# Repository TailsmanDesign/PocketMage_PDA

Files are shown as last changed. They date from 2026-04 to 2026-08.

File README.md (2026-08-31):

# PocketMage PDA
PocketMage is available on Crowd Supply! Check it out [here](https://pocketmage.org/back)!

@Ashtf 2025





## [Project Summary]

  This project is a PDA powered by an ESP32-S3 running a custom OS written in C++ using PlatformIO. This project utilizes an E-Ink and OLED screen in tandem to mitigate the refresh rate restrictions of an E-Ink panel while retaining the aesthetics and benefits of using E-Ink. This project is a work in progress and currently amounts to a simple GUI for navigating between apps, a text (.txt) file editor, and a basic file manager. More applications are planned for the future and a list of TO-DOs can be found below.

  At this point, the plan for this project is to get the software and hardware to maturity and once a finished product is achieved, a few things will happen. First, the project files (Code, KiCad schematics, 3D files) will be open-sourced and free for anyone to access. Next, I will likely begin selling kits that allow people to purchase all the parts required to build a device for themselves if they don't want to source the parts themselves. Finally, the community will be encouraged to help develop the software for the device and hopefully push it even further than I could myself.

  I will try my best to keep this GitHub up to date with the development of the device.

## [Getting Started]

Start with the docs site:

- [PocketMage Docs](https://talismandesign.github.io/PocketMage_PDA/docs/)
- [Build Environments](https://talismandesign.github.io/PocketMage_PDA/docs/development/build-environments)
- [Command Manual](https://talismandesign.github.io/PocketMage_PDA/docs/command-manual)
- [FAQ](https://talismandesign.github.io/PocketMage_PDA/docs/faq)
- [Scripting](https://talismandesign.github.io/PocketMage_PDA/docs/scripting)
- [App API Reference](https://talismandesign.github.io/PocketMage_PDA/docs/reference/app-api)

To build or extend apps, start with [APP_TEMPLATE.cpp](./Code/PocketMageOS/src/APP_TEMPLATE.cpp) and the [App API Reference](https://talismandesign.github.io/PocketMage_PDA/docs/reference/app-api).
The app walkthrough video is still useful for a first pass:
[Developing For the PocketMage](https://www.youtube.com/watch?v=3Ytc-3-BbMM)

## [Hardware]

- ESP32-S3 WROOM1 with 16 MB flash and 8 MB RAM. WiFi and Bluetooth supported.
- 3.1" 320x240px 1-bit SPI E-Ink panel (GDEQ031T10) with integrated driver
- 256x32px 1-bit SPI OLED (SSD1326, ER-OLED018-1W) with integrated driver
- MicroSD card slot with support for up to 2 TB
- TCA8418 I2C keyboard matrix IC
- Piezo buzzer (simple tones)
- Power button
- 1200 mAh pouch-style LiPo battery with JST PH (2 mm) connector
- USB Type-C connector
- PCF8563T I2C RTC module
- Expansion port with the following breakouts:
  - +3.3V
  - GND
  - I2C SDA
  - I2C SCL
  - SPI MOSI
  - SPI SCK
  - SPI MISO
  - GPIO A
  - GPIO B
  - GPIO C
  - GPIO D / UART TX (changeable with a solder jumper, default TX)
  - GPIO E / UART RX (changeable with a solder jumper, default RX)

## [Software]

- Text editor app (TXT)
- FileWiz file-management app
- Calendar app
- USB file transfer app
- COMM mesh chat app
- Settings app
- Tasks app
- Journal app
- Dictionary app (Lexicon)
- App loader for OTA apps
- Terminal app (Wrench scripting)
- SSH
- Commands supported through the home menu:
  - `roll dN` (dice roll, N = number of sides)
  - set time and date
  - directly open files in TXT or FileWiz by typing the name
  - and more

## [Planned Features]

- Timers and alarms
- E-book reader
- WiFi notes/calendar sync (Google Docs/Calendar)
- LoRa/Meshtastic add-on module
- Battery expansion add-on module
- Custom abbreviations
- Bluetooth keyboard support

## License

All files are distributed under the Apache-2.0 license:

PocketMage PDA - A clamshell note-taking and productivity device using E-Ink and OLED.



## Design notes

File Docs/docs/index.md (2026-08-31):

---
title: "PocketMage Documentation"
description: "Official documentation for the PocketMage open-source PDA device."
---

# PocketMage Documentation

PocketMageOS docs for the clamshell PDA, the reusable PocketMage Library, and the app workflow built on top of both.

::: tag "PocketMageOS"
::: tag "PocketMage Library"
::: tag "Apps"
::: tag "Commands"

## What is here

::: grids
::: grid
::: card "Getting Started" icon:rocket
Learn what PocketMage is, how to build it, and where to begin.

::: button "Open" ./getting-started/index.md icon:arrow-right
:::
:::
::: grid
::: card "PocketMageOS" icon:cpu
The operating system, app runtime, and navigation flow.

::: button "Open" ./development/index.md icon:arrow-right
:::
:::
::: grid
::: card "Guides" icon:book-open
How to make apps, native apps, OTA apps, and scripts.

::: button "Open" ./guides/index.md icon:arrow-right
:::
:::
::: grid
::: card "Reference" icon:code
The app API, PocketMage Library, and system state.

::: button "Open" ./reference/index.md icon:arrow-right
:::
:::
::: grid
::: card "Commands" icon:keyboard
Keymaps and built-in commands for every app.

::: button "Open" ./command-manual/index.md icon:arrow-right
:::
:::
::: grid
::: card "Features" icon:star
What the device does today and what is still planned.

::: button "Open" ./features/index.md icon:arrow-right
:::
:::
:::

## Quick path

::: steps

1. Read [What is PocketMage](getting-started/what-is-pocketmage.md).
2. Set up the firmware build in [Build Environments](development/build-environments.md).
3. Learn the app model in [Making Apps](guides/making-apps.md).
4. Use the [PocketMage Library](reference/pocketmage-library.md) when you need the hardware wrapper.
5. Keep the [Command Manual](command-manual/index.md) open while testing apps.

:::

## Quick links

- [FAQ](faq/index.md)
- [Scripting](scripting/index.md)
- [GitHub Repository](https://github.com/TalismanDesign/PocketMage_PDA)
- [Discord Community](https://discord.gg/KSCapSf4XH)

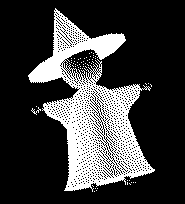
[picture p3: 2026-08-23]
Resources/Assets/Onboarding/onboardMage.bmp

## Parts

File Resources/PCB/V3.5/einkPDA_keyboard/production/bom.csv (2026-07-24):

Designator | Footprint | Quantity | Value | LCSC Part #
BZ1 | BUZ-SMD_3P_L5.0-W5.0-P3.50-TL | 1 | Buzzer | C781883
C1, C20, C4, C6 | 0603 | 4 | 1uF | C15849
C10, C23, C24, C26, C28, C29, C30, C31, C32 | 0805 | 9 | 10uF | C15850
C11 | 0603 | 1 | 4.7pF | C1669
C12, C13, C14, C16 | 1206 | 4 | 4.7uF | C29823
C15, C17 | 0805 | 2 | .1uF | C28233
C18 | 0805 | 1 | 680pF | C1754
C19, C33, C7, C8 | 0402 | 4 | 0.1uF | C1525
C2, C9 | 0805 | 2 | 100nF | C49678
C21, C22, C3 | 0805 | 3 | 22uF | C45783
C25 | 0805 | 1 | 4.7uF | C1779
C27 | 0603 | 1 | 22nF | C21122
C5 | 0805 | 1 | 47uF | C124129
D1 | 0805 | 1 | KT-0805Y | C2296
D2 | D_SOD-123 | 1 | MBR0530 | C77336
D3 | D_SOD-123F | 1 | SM4007 | C64898
D5 | D_SOD-323 | 1 | D_Schottky | C191023
F1 | 1206 | 1 | SMD1206-500-6V | C2760308
FB1, FB2, FB3 | 0603 | 3 | FerriteBead | C85831
J1 | USB-TYPE-C-SMD_TYPE-C-16P-QTWT | 1 | USB_C_Receptacle_USB2.0_16P | C5187472
J2, J5 | AFC01-S12FCA-00 | 2 | Conn_01x12_Pin | C262661
J3 | FPC-SMD_AFC24-S26FIA [DUAL-SIDE] | 1 | Conn_01x26_Pin | C262684
J4 | TF-SMD_503398-1892 | 1 | Micro_SD_Card | C428492
L1 | L_Chilisin_BMRx00060630 | 1 | 10uH | C5189958
L2 | L_Ferrocore_DLG-0504 | 1 | 1uH | C2929426
L3 | L_Wurth_WE-LQSH-3012 | 1 | 2.2uH | C167747
Q1 | SOT-23 | 1 | MMBT3904 | C20526
R1, R14, R17 | 0805 | 3 | 10K | C17414
R11, R16 | 0805 | 2 | 2k | C17604
R12 | 0805 | 1 | 1.8M | C17399
R13 | 0805 | 1 | 205k | C218417
R15, R5 | 0805 | 2 | 470R | C17710
R18 | 0603 | 1 | 10k | C25804
R19, R6, R7 | 0603 | 3 | 100K | C25803
R2, R8 | 0603 | 2 | 100R | C22775
R20 | 0805 | 1 | 680k | C17797
R3 | 0603 | 1 | 4.7k | C23162
R4 | 0603 | 1 | 1k | C21190
RN1, RN2, RN3, RN4, RN5 | R_Array_Concave_4x0603 | 5 | 4x10k | C29718
SW1, SW10, SW11, SW12, SW13, SW14, SW15, SW16, SW17, SW18, SW19, SW20, SW21, SW22, SW23, SW24, SW25, SW26, SW27, SW28, SW29, SW3, SW30, SW31, SW32, SW33, SW34, SW35, SW37, SW38, SW39, SW40, SW5, SW6, SW7, SW9 | contact_pad_SINGLE | 36 | ~
SW2 | contactPad_cutoutR | 1 | ~
SW36, SW41 | KEY-TH_3P-L4.5-W4.5-P3.0-EH | 2 | YTS-C017-2B | C2910872
SW4 | 2X_DIP_DHN-02-V-TR | 1 | SW_DIP_x02 | C224995
SW8 | contactPad_cutoutL | 1 | ~
TH1 | 0603 | 1 | NTC | C76589
TP1, TP2 | TestPoint_Pad_1.0x1.0mm | 2 | TestPoint
U1 | ESP32-S3-WROOM-1 | 1 | ESP32-S3-WROOM-1-N16R2 | C2913205
U10 | UQFN-10_1.4x1.8mm_P0.4mm | 1 | TS3USB30ERSWR | C73880
U2 | SOT-23-6 | 1 | USBLC6-2SC6 | C7519
U3 | Texas_DRC0010J_ThermalVias | 1 | TPS63001 | C28060
U4 | SOIC-8_3.9x4.9mm_P1.27mm | 1 | PCF8563T | C7440
U5 | RTW24_2P45X2P45 | 1 | TCA8418RTWR | C138713
U6 | JST_PH_2P_P2.00mm | 1 | C2764211 | C2764211
U7 | SOT-23-5 | 1 | TPS61040DBV | C7722
U8 | SOT-23-6 | 1 | TPS22917DBV | C2680344
U9 | IC_MP2722GRH-0000-Z | 1 | MP2722GRH-0000-Z | C20099551
Y1 | Crystal_SMD_3215-2Pin_3.2x1.5mm | 1 | Crystal_32.768kHz | C5213671

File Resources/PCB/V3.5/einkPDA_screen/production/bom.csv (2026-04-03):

Designator | Footprint | Quantity | Value | LCSC Part #
C1, C10, C3, C4, C5, C6, C7, C8, C9 | 0402 | 9 | 1uF | C52923
C11 | 0805 | 1 | 4.7uF | C1779
C12, C2 | 0402 | 2 | 4.7uF | C23733
C13, C14 | 0402 | 2 | 0.1uF | C1525
D1, D2, D3 | D_SOD-123 | 3 | MBR0530 | C77336
J2 | AFE03-S25FMA-1H | 1 | ~ | C262544
J3 | TouchSlider-9_50x10mm | 1 | CapacitiveTouch
J4 | AFC01-S12FCA-00 | 1 | Conn_01x12_Pin | C262661
L1 | L_Cenker_CKCS5020 | 1 | 10uH | C52281
Q1 | SOT-323_SC-70 | 1 | Si1308EDL | C7603347
R1 | 0603 | 1 | 0.47R | C3013349
R2 | 0805 | 1 | 10k | C17414
R3 | 0603 | 1 | 75k | C23242
RN1 | R_Array_Concave_4x0603 | 1 | 4x10k | C29718
U1 | UQFN-20_3x3mm_P0.4mm | 1 | MPR121QR2 | C91322

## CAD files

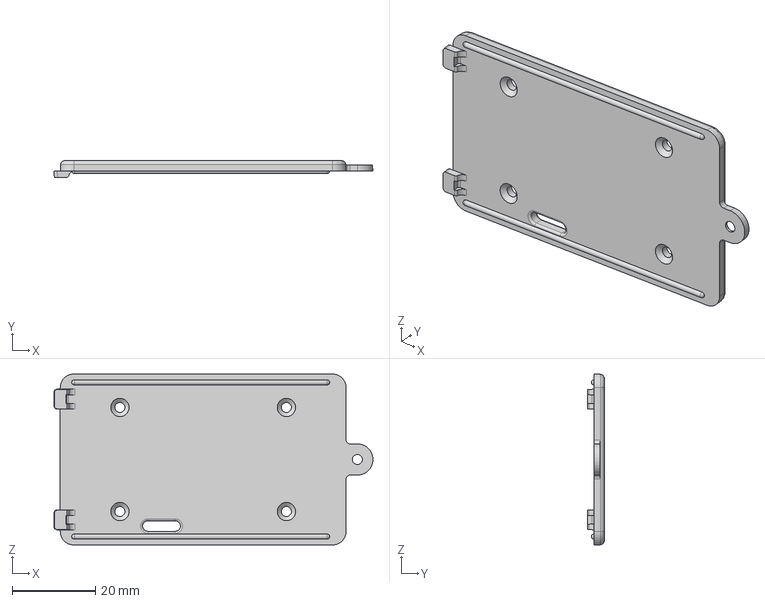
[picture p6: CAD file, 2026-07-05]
Resources/CAD/V3.4 FDM Friendly/batteryDoorFDM.step
76.6 x 4.00 x 41.1 mm

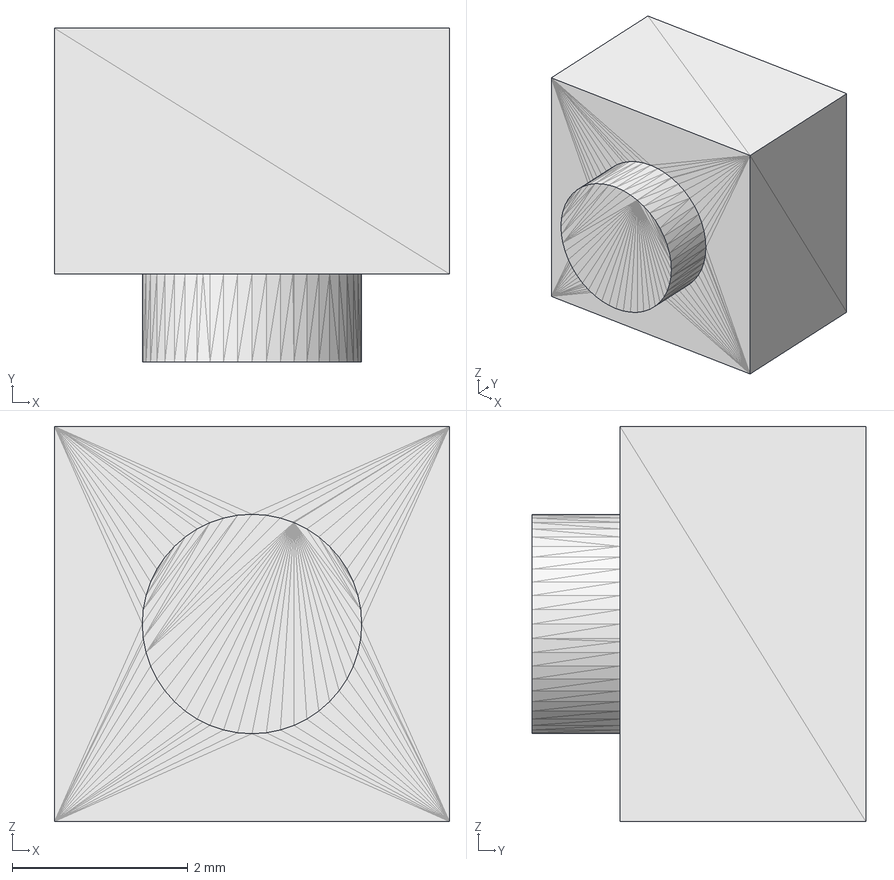
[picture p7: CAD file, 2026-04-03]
Resources/PCB/V3.5/einkPDA_keyboard/JLC_Parts/YTS-C017-2B.step
4.50 x 3.80 x 4.50 mm

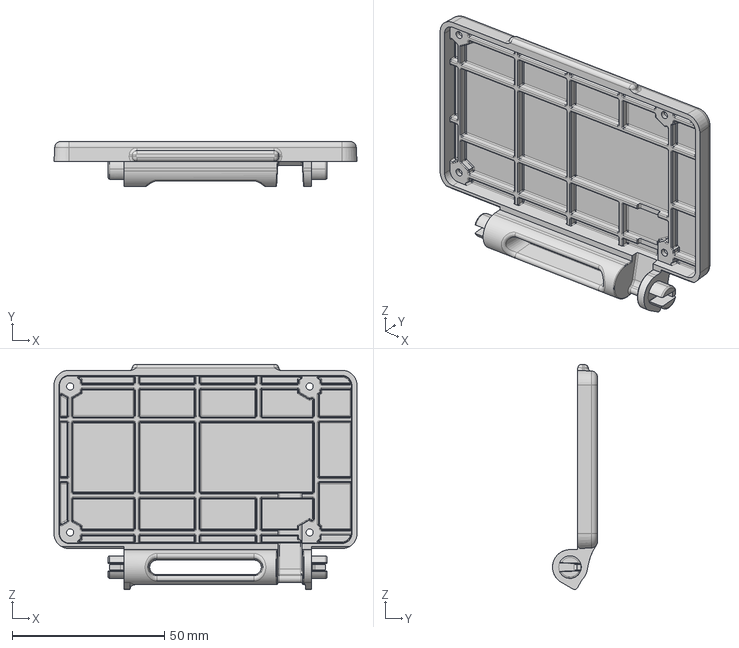
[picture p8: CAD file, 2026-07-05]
Resources/CAD/V3.4 FDM Friendly/frameLidFDM.step
99.6 x 14.8 x 74.0 mm

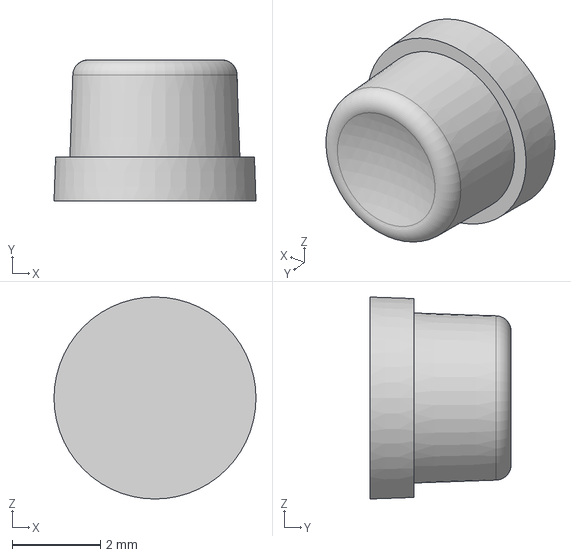
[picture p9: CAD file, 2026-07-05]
Resources/CAD/V3.4 FDM Friendly/resetButtonFDM.step
4.57 x 3.20 x 4.57 mm

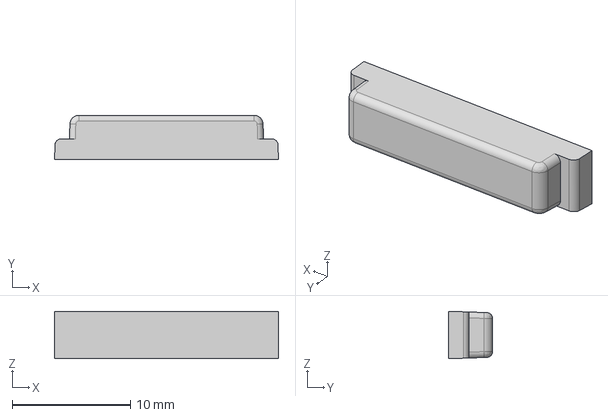
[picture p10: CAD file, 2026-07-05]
Resources/CAD/V3.4 FDM Friendly/powerButtonFDM.step
19.0 x 3.75 x 4.02 mm

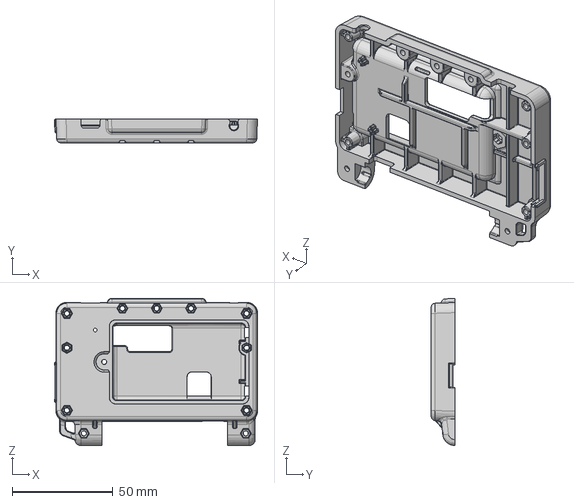
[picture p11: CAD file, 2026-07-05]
Resources/CAD/V3.4 FDM Friendly/bottomFrameFDM.step
100.5 x 11.7 x 72.8 mm

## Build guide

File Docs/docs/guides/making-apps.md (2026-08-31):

---
title: "Making Apps"
description: "How to create PocketMage apps, both native and OTA."
---

# Making Apps

PocketMage apps come in two forms: native apps that ship inside PocketMageOS, and OTA apps that are loaded onto the device later. The two share the same core shape, so this page walks through that shape once and then explains where the paths diverge.

::: grids
::: grid
::: card "Native apps" icon:terminal
Compiled into the OS and wired into the app dispatch switch.
:::
:::
::: grid
::: card "OTA apps" icon:package
Compiled separately and loaded into one of four OTA slots at runtime.
:::
:::
::: grid
::: card "Same shape" icon:code
Both are three functions: init, handle input, draw.
:::
:::
:::

## The basic app shape

Every PocketMage app has the same three jobs, and they map directly to three functions.

1. **Initialize state** - run once when the app opens. Set up whatever the app needs and mark the screen for a redraw.
2. **Process keyboard input** - run on every keypress. Read the key, update app state, and queue a redraw.
3. **Draw the screen** - run when the E-Ink needs to update. Render the current app state.

This pattern is visible in `Code/PocketMageOS/include/globals.h` (the prototypes) and in the app files under `Code/PocketMageOS/src/OS_APPS/`.

## Start with the template

The app template is your starting point:

- [APP_TEMPLATE.cpp](https://github.com/TalismanDesign/PocketMage_PDA/blob/main/Code/PocketMageOS/src/APP_TEMPLATE.cpp)

It defines the three entry points an OTA app needs:

```cpp
#include <globals.h>
#if OTA_APP
void APP_INIT() {
  // 1. set up app state
}

void processKB_APP() {
  // 2. handle a keypress
}

void einkHandler_APP() {
  // 3. draw the screen
}
#endif
```

## Building the app step by step

1. **Decide native vs OTA.** If the app belongs to the device experience, make it native. If it is third-party or experimental, make it an OTA app so it can be installed and removed without reflashing the OS.
2. **Pick the shared helpers.** Browse the [PocketMage Library](../reference/pocketmage-library.md) before writing anything. Prompts (`textPrompt()`), file selection (`fileWizardMini()`), and timeouts (`checkTimeout()`) already exist; do not reimplement them.
3. **Wire it into the OS (native only).** Add an `AppState` entry, the three prototypes, and the `switch` cases marked `// ADD APP CASES HERE` in `PocketMageV3.cpp`. Then add a home-screen command if you want it launchable by name.
4. **Test the keyboard path first.** Get a keypress into your handler and onto the OLED before worrying about the E-Ink.
5. **Test the E-Ink path second.** Make sure drawing and refresh behave, including fast partial refreshes.
6. **Check timeout, wake, and save last.** Confirm the app resets the idle clock, handles sleep/wake without corrupting state, and saves before exit where it should.

## Good app rules

- Keep app state local and explicit; do not scatter globals.
- Use shared helpers instead of duplicating them.
- Keep draw code separate from input code.
- Make exit, save, and sleep behavior obvious.
- For native apps, follow the existing app in `src/OS_APPS/` that does the closest job.

## Native vs OTA: which path

| | Native | OTA |
| --- | --- | --- |
| Where the code lives | `src/OS_APPS/` inside PocketMageOS | Standalone project using `APP_TEMPLATE.cpp` |
| How it is built | With the OS (`PM_PRODUCTION`/`PM_BETA`) | With the `OTA_APP` environment |
| How it ships | Flashed as part of the firmware | Packaged as a `.tar` and loaded through the app loader |
| Dispatch | Wired into the switch in `PocketMageV3.cpp` | Entry points called by the loader |
| Hardware access | PocketMage Library | PocketMage Library |

Read the [Native Apps](native-apps.md) and [OTA Apps](ota-apps.md) pages for the details of each path.

## Next steps

::: grids
::: grid
::: button "Native Apps" ./native-apps.md icon:terminal
:::
::: grid
::: button "OTA Apps" ./ota-apps.md icon:package
:::
::: grid
::: button "App API Reference" ../reference/app-api.md icon:book
:::
::: grid
::: button "PocketMage Library" ../reference/pocketmage-library.md icon:box
:::
:::

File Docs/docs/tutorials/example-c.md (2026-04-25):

---
title: "PocketMage Script Example: Basic Input/Output"
description: "A simple PocketMage script demonstrating user input, OLED output, and terminal printing."
---

# Scripting Example: Basic Input/Output

```c
// PocketMage scripting example
// Based on Wrench by jingoro2112 (GH)
// Edit with potion: pot example.c
// Compile and run: brew example.c

// Declare a variable
var x = ""; // "" indicates str

// Prompt user to enter number
// Set x to entered number
x = prompt("Enter a number");

// Display x on OLED
oledWord(x);

// Print x to terminal
print(x);

// Update the terminal
// (refresh the OLED)
updateTerm();

// Initialize an iteration var i
var i = 0;

// Loop while i < x
// Us toInt to convert str to int
while (i < toInt(x)) {
  // Iterate
  i = i + 1;

  // Display i on OLED
  oledWord(i);

  // Wait 500ms
  delay(500);
}

// Print the final i to the term
print(i);

// Generate a random number
var randomInt = random(0, 100);
print("Random Number: " + randomInt);

// Update the terminal
// (refresh the OLED)
updateTerm();
```

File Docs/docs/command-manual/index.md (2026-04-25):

---
title: "PocketMage Command Manual"
description: "Keystrokes and command reference for the PocketMage PDA."
---

# PocketMage Keystrokes Guide

This is a guide on common key combinations and commands on the PocketMage PDA device. The guide is split up into sections based on application.

---

## General Keystrokes (work in almost any app)

- **( < )** | Cursor left
- **( > )** | Cursor right
- **(SHIFT) + ( < )** | Cursor to start of line
- **(SHIFT) + ( > )** | Cursor to end of line
- **(FN) + ( o )** | Clear line
- **(FN) + ( < )** | Exit or back button
- **(FN) + ( > )** | Save document
- **(SHIFT) + (key)** | Capital letter
- **(FN) + (Key)** | FN layer keymapping (legends on the PCB)
- **(FN) + (SHIFT) + (Key)** | FN+SHIFT layer keymapping
- **( o ) OR (ENTER)** | Select button

---

## Keymap

### Default Layer

```txt
[q] [w] [e] [r] [t] [y] [u] [i] [o] [p]
[a] [s] [d] [f] [g] [h] [j] [k] [l] [BKSP]
[TAB] [z] [x] [c] [v] [b] [n] [m] [.] [ENTER]
[SHIFT] [FN] [SPACE] [<] [o] [>]
```

### Shift Layer

```txt
[Q] [W] [E] [R] [T] [Y] [U] [I] [O] [P]
[A] [S] [D] [F] [G] [H] [J] [K] [L] [BKSP]
[TAB] [Z] [X] [C] [V] [B] [N] [M] ['] [ENTER]
[SHIFT] [FN] [SPACE] [SHIFT+<] [SHIFT+o] [SHIFT+>]
```

### Function Layer

```txt
[1] [2] [3] [4] [5] [6] [7] [8] [9] [0]
[#] [!] [$] [:] [;] [(] [)] [&] ["] [BKSP]
[FN+TAB] [%] [_] [+] [-] [*] [/] [?] [,] [ENTER]
[SHIFT] [FN] [SPACE] [FN+<] [FN+o] [FN+>]
```

### Function + Shift Layer

```txt
[!] [@] [#] [$] [%] [^] [&] [*] [(] [)]
[~] [`] [|] [[] []] [{] [}] [<] [>] [BKSP]
[FN+TAB] [%] [=] [&] [+] [-] [\] [?] [,] [ENTER]
[SHIFT] [FN] [SPACE] [FN+SHIFT+<] [FN+SHIFT+o] [FN+SHIFT+>]
```

---

## While Sleeping

### Bypass home and directly enter an app

You can bypass the home menu and enter directly into an app and wake up with one keystroke. Pressing the buttons below while PocketMage is sleeping will wake the device and boot into the corresponding app.

- **( SPACE )** - Return to previous app (saved state from last sleep)
- **( H )** - Home
- **( U )** - USB
- **( F )** - Filewiz
- **( T )** - Tasks
- **( N )** - TXT
- **( S )** - Settings
- **( C )** - Calendar
- **( J )** - Journal
- **( D )** - Dictionary (lexicon)
- **( L )** - Loader

---

## Home App

### Entering an OS app

Type an app's name to enter that app. For example, to enter calendar, type "calendar". You can type the name as it appears on the screen or use a shortcut. For example, typing "cal" also enters the calendar.

### Entering a 3rd party app

For 3rd party apps, type the letter of the slot that app is installed in. For example if you have the Calc app installed in the first app slot, type "a" to enter the app.

### Other commands

Many other commands can be done from the homescreen, including all of the settings commands and some other fun ones for you to discover!

---

## TXT App

- **(FN) + ( < )** | Exit app
- **(FN) + ( > )** | Save document
- **(FN) + ( o )** | Enter filesystem (loading files)
- **(SHFT) + ( o )** | New blank text document
- **(FN) + (Key)** | FN layer keymapping (legends on the PCB)
- **(SHFT) + (key)** | Capital letter
- **(ENTER)** | Create a new line
- **(SHFT) + ( < )** | Change text style (body, heading, etc.)
- **(SHFT) + ( > )** | Change formatting (bold, italics, etc.)
- **Scroll Bar** | Swipe up or down to scroll through the document

---

## FILEWIZ

- **(FN) + ( < )** | Exit app
- **( < ) AND ( > )** | Scroll left and right
- **( o ) OR (ENTER)** | Select file or folder
- **( 0 ) TO ( 9 )** | Select recent file
- **( BKSP )** | Go back a filesystem level

---

## USB

Plug in the PocketMage to your PC to view the files. Eject and exit the app when you're finished.

- **(FN) + ( < )** | Exit app

---

## Settings

Type the setting as it appears on the screen to change it. Some examples are given below. Note: all settings are case-insensitive, meaning that you can type in all lowercase. All of these settings are also available from the home menu command bar if you memorize them.

- TimeSet [HH]:[MM] -> TimeSet 15:46
- DateSet YYYYMMDD -> DateSet 20251230
- ShowYear [bool] -> ShowYear t
- Timeout [int] -> Timeout 300
- **(FN) + ( < )** | Exit app

---

## Tasks

- **( N )** | Create a new task, follow on-screen prompts
- **(ENTER)** | Enter information into prompt
- **( 0 ) TO ( 9 )** | Select task for editing
- **(FN) + ( < )** | Exit app

---

## Calendar

Type commands to navigate dates or create events. All commands are case-insensitive.

### Month View

- **jan 2025 / feb 2030 / etc.** | Jump to month and year
- **20251225** | Jump to exact date (YYYYMMDD)
- **14** | Jump to a day in the current month
- **( N )** | New event
- **(FN) + ( < )** | Exit app

### Week View

- **sun, mon, tue, wed, thu, fri, sat** | Jump to weekday in the viewed week
- **( N )** | New event
- **(FN) + ( < )** | Exit app

### Day View

- **( N )** | New event for selected day
- **1, 2, 3, ...** | Open event by index
- **(FN) + ( < )** | Exit app

### Repeating Events

- **no** | No repeat
- **daily** | Repeat every day
- **weekly xx** | Repeat every week, **xx** is one or more of **mo**, **tu**, **we**, **th**, **fr**, **sa**, **su**
- **monthly xx** | Repeat monthly, **xx** is the day of the month (1-31) or ordinal weekday (ex. **2tu** = the second Tuesday of each month)
- **yearly xx** | Repeat every year, **xx** is month and day of the month (ex. **apr22**)

---

## Journal

Type a date to open or create a journal entry. Commands are case-insensitive.

- **( T )** | Open today’s journal entry
- **YYYYMMDD - Example: 20250314** | Open/create entry for exact date
- **jan 1 / feb 12 / etc.** | Open/create entry for given month and day (uses current year)
- **(FN) + ( < )** | Exit app

---

## Lexicon

Type a word to search the dictionary. Matches are loaded from the SD card. Commands are case-insensitive.

- **Type any word** | Search for definitions (example: abandon)
- **(ENTER)** | Execute search
- **( < ) OR ( > )** | Previous / next definition
- **(FN) + ( < )** | Exit app

---

## App loader

Manage and install .tar apps to OTA slots. Commands are case-insensitive.

- **A / B / C / D** | Select OTA slot to edit
- **( S )** | Swap app in selected slot (choose a .tar file)
- **( D )** | Delete app in selected slot
- **(FN) + ( < )** | Exit app / return to menu
- **Progress Bar** | Shows extraction (0–50%) and installation (50–100%) status

---

## Sleep Modes

When on battery, save power and look at a random screensaver. When charging, view a clock, upcoming tasks, and weather (work in progress)

### Sleep (when not plugged into usb)

- **sleep button** to enter sleep
- **any key on keyboard** to wake

### Now-Later (when usb is plugged in)

- **sleep button** to enter now-later
- **sleep button** to wake

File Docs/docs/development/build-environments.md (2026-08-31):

---
title: "Build Environments & PlatformIO Setup"
description: "How to set up PlatformIO and build PocketMage firmware on Linux, macOS, and Windows."
---

# Build Environments & PlatformIO Setup

PocketMage firmware is built with [PlatformIO](https://platformio.org/). The build configuration lives in `Code/PocketMageOS/platformio.ini` and defines three environments that produce different firmware images from the same source.

## The three build environments

| Environment | Target | Purpose |
| --- | --- | --- |
| `PM_PRODUCTION` | Production hardware (N16R2, Quad PSRAM enabled) | The stable OS image flashed to production devices |
| `PM_BETA` | Beta hardware (N16R8, PSRAM forced disabled) | A test build with the latest changes |
| `OTA_APP` | Hardware-agnostic | A single third-party app built to be sideloaded |

The three environments share a common `[common]` section and differ only in build flags. The flags set three things: which hardware revision to target, whether the build is an OS or an OTA app, and the version string.

Running `pio run` with no arguments builds all three. Build one explicitly with `pio run -e <name>`.

### What the OTA_APP flag does

The `OTA_APP` environment defines `OTA_APP_FLAG=1`. In `config.h` this becomes `OTA_APP == true`, which excludes the native OS app set from the build. The three entry points from [APP_TEMPLATE.cpp](https://github.com/TalismanDesign/PocketMage_PDA/blob/main/Code/PocketMageOS/src/APP_TEMPLATE.cpp) - `APP_INIT()`, `processKB_APP()`, `einkHandler_APP()` - become the program. The same source tree therefore builds either a full OS or a standalone app depending on the environment you choose.

## Prerequisites

- [VS Code](https://code.visualstudio.com/) installed
- Python 3 installed
- PlatformIO Core (installed automatically by the VS Code extension, or via `pip install platformio`)
- The PocketMage source code, cloned from [GitHub](https://github.com/TalismanDesign/PocketMage_PDA)

The ESP32 platform support downloads automatically on the first build, so the first build is noticeably slower.

## Setup

### Linux

1. Install `python3-venv` if it is missing:

   ```bash
   sudo apt install python3-venv
   ```

2. Install the [PlatformIO IDE](https://docs.platformio.org/en/latest/integration/ide/vscode.html#ide-vscode) extension in VS Code.
3. Open the PocketMage source folder in VS Code.
4. When PlatformIO asks for a project folder, choose `Code/PocketMageOS/`.
5. Build from the PlatformIO toolbar or the command palette.

### macOS

Use the same steps as Linux. No extra setup is required.

### Windows

1. Install [Git](https://git-scm.com/) to clone the repository.
2. Follow the same PlatformIO IDE steps as Linux.
3. Build from the PlatformIO toolbar in VS Code.

## Command line

From `Code/PocketMageOS/`:

```bash
pio run -e PM_PRODUCTION   # production firmware
pio run -e PM_BETA         # beta firmware
pio run -e OTA_APP         # a third-party OTA app
```

## OTA apps

OTA apps use the `OTA_APP` environment, which switches the build into app mode as described above. The app is packaged as a `.tar` file and installed on the device through the app loader. See [OTA Apps](../guides/ota-apps.md) and the [app loader section](../command-manual/index.md) of the command manual.

For a full walkthrough, watch the [OTA app development video](https://www.youtube.com/watch?v=3Ytc-3-BbMM).

## Testing

There is no automated test suite for the firmware. Verify changes against real hardware, or review the build log for changes with no runtime effect. CI builds `PM_PRODUCTION` and `PM_BETA` on every push, so a clean build locally is the minimum bar before opening a pull request.

## Next steps

::: grids
::: grid
::: button "PocketMageOS overview" ./index.md icon:cpu
:::
::: grid
::: button "Making Apps" ../guides/making-apps.md icon:code
:::
::: grid
::: button "OTA Apps" ../guides/ota-apps.md icon:package
:::
::: grid
::: button "Firmware FAQ" ../faq/index.md icon:help-circle
:::
:::

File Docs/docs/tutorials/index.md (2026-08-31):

---
title: "PocketMage Tutorials"
description: "Step-by-step guides for PocketMage setup and configuration."
---

# Tutorials

These pages cover hands-on setup tasks.

## Guides

- [Format a MicroSD Card](format-micro-sd.md)

## Development

- [Build Environments & PlatformIO Setup](../development/build-environments.md)
- [OTA App Template](https://github.com/TalismanDesign/PocketMage_PDA/blob/main/Code/PocketMageOS/src/APP_TEMPLATE.cpp)

## Scripting

- [Scripting Overview](../scripting/index.md)
- [Full Wrench Command List](../scripting/fullPotionCommandList.md)

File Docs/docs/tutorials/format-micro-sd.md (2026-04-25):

---
title: "Format a MicroSD Card for PocketMage"
description: "Guide to formatting SD cards for compatibility with PocketMage."
---

# PocketMage SD Card Formatting Guide

**WARNING**  
These steps will ERASE the SD card. Back up your data first.

This guide ensures SD cards are formatted in a way that is compatible with the PocketMage device.

---

## Supported SD Card Requirements

- **Card size:** 2 GB – 32 GB microSD
- **Filesystem:** FAT32
- **Partition scheme:** MBR (Master Boot Record)
- **Partitions:** Single primary partition
- **Cluster (allocation unit) size:** 32 KB
- **Sector size:** 512 bytes (default)

X exFAT is NOT supported  
X GPT partition tables are NOT supported  
X 64 GB+ cards are NOT recommended unless you explicitly force FAT32 + MBR

---

## Windows (Recommended)

### Step 1 — Open diskpart

1. Insert the SD card
2. Open **Command Prompt as Administrator**
3. Run:
   diskpart

### Step 2 — Identify the SD card

list disk

Find the disk number that matches your SD card size.

**Make sure you select the correct disk.**

### Step 3 — Format the card (MBR + FAT32)

select disk X
clean
convert mbr
create partition primary
format fs=fat32 unit=32k quick
assign
exit

### Step 4 — Verify (optional)

- Open **Disk Management**
- Right-click the disk → Properties → Volumes
- Partition style must say **Master Boot Record (MBR)**

---

## macOS (Terminal — NOT Disk Utility)

macOS Disk Utility often creates GPT layouts that do not work.

### Step 1 — Identify the SD card

diskutil list

Find the disk number (example: disk2).

### Step 2 — Erase and create MBR + FAT32

diskutil eraseDisk FAT32 PM_SD MBRFormat /dev/disk2

### Step 3 — Force 32 KB cluster size

sudo newfs_msdos -F 32 -c 64 /dev/disk2s1

Explanation:  
-c 64 = 64 × 512-byte sectors = 32 KB clusters

### Step 4 — Verify

diskutil info /dev/disk2 | grep "Partition Map"

Must say:
Partition Map Scheme: Master Boot Record

---

## Linux

### Step 1 — Identify the SD card

lsblk

Example device: /dev/sdb

### Step 2 — Remove existing partition data

sudo wipefs -a /dev/sdb

### Step 3 — Create MBR partition table

sudo parted /dev/sdb --script mklabel msdos
sudo parted /dev/sdb --script mkpart primary fat32 1MiB 100%

### Step 4 — Format FAT32 with 32 KB clusters

sudo mkfs.fat -F 32 -s 64 /dev/sdb1

### Step 5 — Verify

lsblk -o NAME,SIZE,PTTYPE

PTTYPE must be dos.

---

## Final Checklist

Before using the card in PocketMage, confirm:

- FAT32 filesystem
- MBR partition table (not GPT)
- One primary partition
- 32 KB cluster size
- Card size ≤32 GB

If any of these are incorrect, the card may not be detected.

---

If issues persist after following this guide, the SD card itself may be incompatible.

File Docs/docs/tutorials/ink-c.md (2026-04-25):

---
title: "PocketMage Script Example: E-Ink Drawing"
description: "A PocketMage script demonstrating drawing shapes and text on the E-Ink display."
---

# Scripting Example: E-Ink Drawing

```c
// PocketMage E-Ink scripting example
// Based on Wrench by jingoro2112 (GH)
// Edit with potion: pot ink.c
// Compile and run: brew ink.c
// Colors/clr: 1 - Black, 0 - White

delay(1000);

// Draw shapes on a white background
inkBackground(0); //Background clr
inkRect(10, 20, 50, 25, 1, 0); //x,y,w,h,line clr,fill clr
inkCircle(100, 50, 30, 1, 1); //x,y,r,line clr,fill clr
inkText(10, 100, 2, 1, "PocketMage!"); //x,y,font size,text
updateInk(); //Update E-Ink display

delay(3000);

// Draw shapes on a black background
inkBackground(1); //Background clr
inkRect(20, 10, 25, 50, 0, 1); //x,y,w,h,line clr,fill clr
inkCircle(120, 60, 35, 0, 0); //x,y,r,line clr,fill clr
inkText(30, 120, 3, 0, "Hello World!"); //x,y,font size,text
updateInk(); //Update E-Ink display

delay(3000);
```

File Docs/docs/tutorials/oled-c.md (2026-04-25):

---
title: "PocketMage Script Example: OLED Drawing"
description: "A PocketMage script demonstrating drawing shapes and text on the OLED display."
---

# Scripting Example: OLED Drawing

```c
// PocketMage OLED scripting example
// Based on Wrench by jingoro2112 (GH)
// Edit with potion: pot ink.c
// Compile and run: brew ink.c
// Colors/clr: 1 - Black, 0 - White

delay(1000);

// Draw shapes on a white background
oledBackground(0); //Background clr
oledRect(10, 20, 25, 5, 1, 0); //x,y,w,h,line clr,fill clr
oledCircle(100, 10, 10, 1); //x,y,r,line clr
oledText(180, 20, 2, 1, "PocketMage!"); //x,y,font size,text
updateOled(); //Update OLED display

delay(3000);

// Draw shapes on a black background
oledBackground(1); //Background clr
oledRect(10, 20, 25, 5, 0, 1); //x,y,w,h,line clr,fill clr
oledCircle(100, 10, 10, 0); //x,y,r,line clr
oledText(120, 20, 3, 0, "Hello World!"); //x,y,font size,text
updateOled(); //Update OLED display

delay(3000);
```

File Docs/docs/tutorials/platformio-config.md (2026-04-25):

---
title: "Setting Up a PocketMage Build Environment"
description: "How to set up PlatformIO and build PocketMage firmware on Linux, Mac, and Windows."
---

# Setting Up a Pocket Mage Build Environment

## Prerequisites

- VS Code is installed.
- python3 is installed.
- You have a directory with the Pocket Mage source code. This could be directly cloned from the main repo. If you plan on contributing back (and you should) this will be simplified if you first fork the repo and then clone from your own fork.

## Set up a Linux Build Environment

The Pocket Mage project has some information about building the project [in this video](https://www.youtube.com/watch?v=3Ytc-3-BbMM). However, there are some assumptions about what you have provisioned that will probably not be true for most viewers. These are the steps to get a functioning PlatformIO environment such that at 1:04 when he says "We're just going to hit this button" you have a button to hit.

1. Note: This step is for **Linux only**. Probably most people who want to build Pocket Mage already have python3 but my Pop_OS Linux Laptop did not have python3-venv by default. I used [these directions](https://github.com/platformio/platformio-core-installer/issues/85) to get that installed.
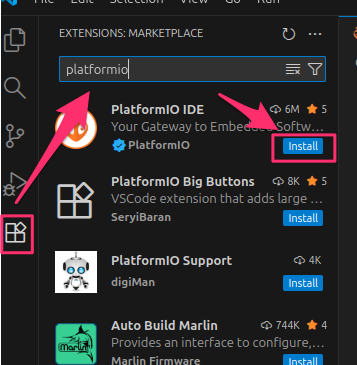
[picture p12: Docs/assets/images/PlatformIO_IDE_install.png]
The Extenstion Marketplace in VS Code
2. You will need the [PlatformIO IDE](https://docs.platformio.org/en/latest/integration/ide/vscode.html#ide-vscode) extension installed in your VS Code. In the Extensions marketplace, search for "PlatformIO IDE" and install it. This will take a little bit of time. After it completes you will be instructed to restart VS Code. 
3. Mark the directory you want to build as a PlatformIO Project.
   - Click the "Pick a Folder" option. You will need an existing platformio.ini config file for this to work. For the first time, try selecting the "BlankApp" folder.

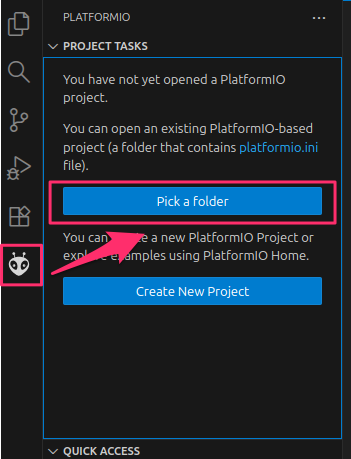
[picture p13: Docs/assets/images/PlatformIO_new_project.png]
The Pick a Folder option in the PlatformIO IDE
   
   - Based on the values of the configuration, many packages will be installed. I found that this took some time with my computer and internet speeds. Expect this to be a good point for a beverage or maybe a meal.

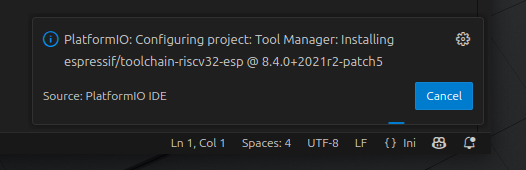
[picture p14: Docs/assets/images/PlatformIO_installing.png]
The status window of PlatformIO creating a project
   

4. Now you can build, by using the drop-down at the upper right.

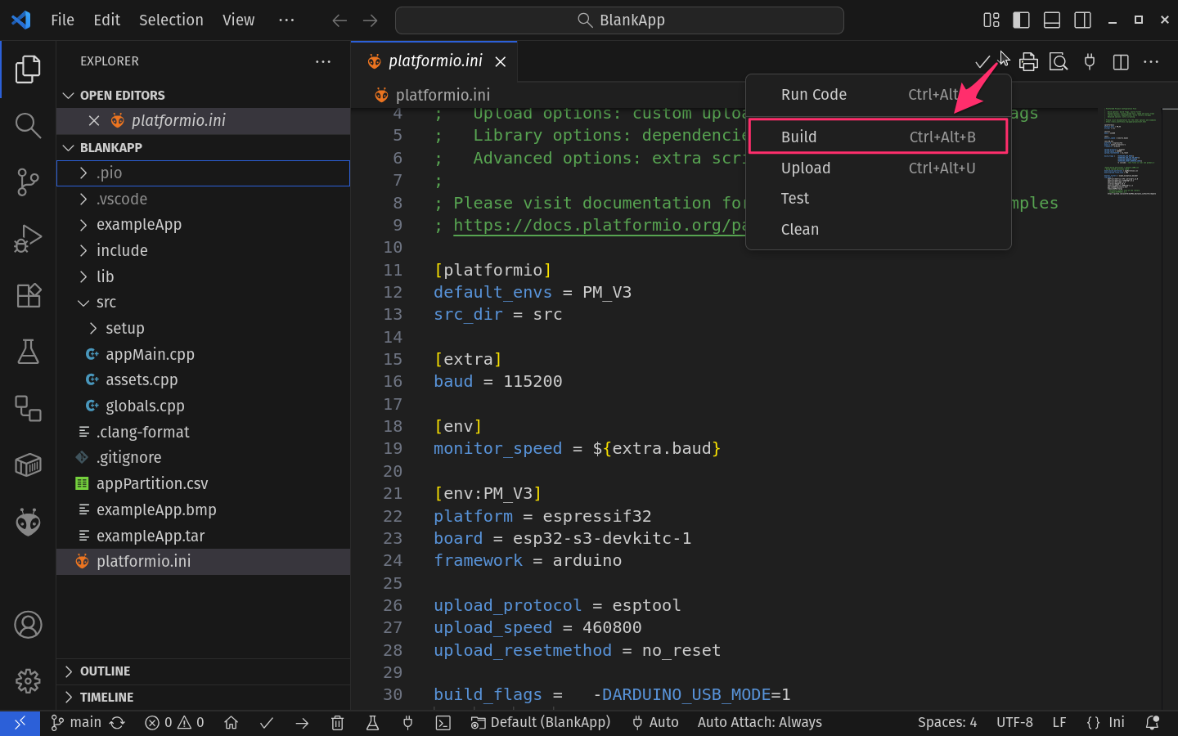
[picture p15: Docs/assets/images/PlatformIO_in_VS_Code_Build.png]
VS Code window configured for PlatformIO build


5. Verify that your environment is working by buildlng either BlankApp or PocketMage_V3. For either, the first compilation will be significantly slower as it builds all the object files for the libraries. Subsequent builds will be much faster.

## Setting up a Macintosh Build Environment

I was able to build both apps using the same directions as Linux.

## Setting up a Windows Build Environment

I was able to build on Windows. However I first had to install Git in order to clone the repository. I initially installed GitHub Desktop but still needed to install Git in order for VS Code to be able to manage the repository. Otherwise the directions above worked.

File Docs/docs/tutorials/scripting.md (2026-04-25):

---
title: "PocketMage Scripting Examples"
description: "Redirect and summary for scripting examples. See individual files for each script."
---

# Scripting Examples

Here are a few examples for the TERMINAL app and scripting.

- [Basic Input/Output Script](example-c.md)
- [E-Ink Drawing Script](ink-c.md)
- [OLED Drawing Script](oled-c.md)

See each file for code and explanations.

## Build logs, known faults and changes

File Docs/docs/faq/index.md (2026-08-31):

---
title: "PocketMage FAQ"
description: "Frequently asked questions about the PocketMage PDA device."
---

# PocketMage FAQ

## Helpful links

- [PocketMage.org](https://pocketmage.org/)
- [PocketMage on GitHub](https://github.com/TalismanDesign/PocketMage_PDA)
- [PocketMage on Discord](https://discord.gg/KSCapSf4XH)
- [Ashtf on YouTube](https://www.youtube.com/@ashtf)
- [Ashtf on Patreon](https://patreon.com/Ashtf)

## General information

### What is PocketMage?

PocketMage is a hackable, open-source PDA focused on productivity. Use it to take notes, keep track of tasks, journal, schedule your week, and more. It is a clamshell design with a clear shell, a full tactile thumb keyboard, a large E-Ink main display, and a smaller OLED secondary display. All hardware and software is open source, which makes it ideal for hacking and add-ons.

### How much is the kit?

The final production kit is not released yet and the price is not final. The target is around $150 for a full kit.

### How hard is it to build the kit?

The kit is designed so anyone can build it. The only tool you need is one allen key, and there is no soldering, programming, or electronics involved in the build process.

### Will I be able to get PocketMage if I live outside the USA?

Yes. We plan to ship worldwide.

### When can I order?

There is no set release date yet. Once the beta production run is complete and the software matures, we will move to final production.

### How can I get notified when the kit releases?

Visit [PocketMage.org](https://pocketmage.org/) and click the "Join the Mailing List!" button.

### How can I keep up with the project?

Subscribe to [Ashtf's YouTube channel](https://www.youtube.com/@ashtf) for video updates, [Ashtf's Patreon](https://patreon.com/Ashtf) for exclusive weekly written updates, and the [PocketMage Discord server](https://discord.gg/KSCapSf4XH) for community updates.

## Building and operating the PocketMage

### Where is the build guide?

The video build guide is [here](https://youtu.be/2aNcC0qCK1o?si=HKqUIyK0ZPkjqzQI).

### Is there a guide on the key operations?

Yes. Use the [Command Manual](../command-manual/index.md).

### How do I flash the firmware?

1. Carefully remove the battery (pull on the plastic connector).
2. Ensure the DIP switch for programming mode is ON.
3. Hold the power button while plugging the PocketMage into your computer. Nothing should happen.
4. Open [The Web Flasher](https://talismandesign.github.io/PocketMage_PDA/) in a Chrome-based browser and select your firmware version. The most recent stable build is recommended.
5. If you want to keep your saved settings, check the "Preserve user data during installation" box.
6. Hit the flash button and select the PocketMage from the list of USB devices.
7. When flashing is done, unplug the PocketMage and re-insert the battery.

PocketMage should boot up automatically.

### What SD card can I use?

Use a microSD card formatted as FAT32 with an MBR partition table. Cards up to 32 GB are recommended; 8 GB is a good sweet spot because PocketMage files are small. The smaller the card, the faster the device. Cards larger than 32 GB must be explicitly forced to FAT32 + MBR and are not recommended. See [Format a MicroSD Card](../tutorials/format-micro-sd.md) for the exact steps.

### Where are the CAD files?

CAD files are available only to beta testers until the final production release. If you are a beta tester, find the password-protected archive [here](https://github.com/TalismanDesign/PocketMage_PDA/tree/main/Resources/CAD) and the password in the beta Discord channel.

### Where can I get an extra battery?

International kits do not come with a battery because of shipping regulations. Battery links for common countries are [here](https://pocketmage.org/get/).

### What is the programming mode switch?

The programming mode switch connects the USB port directly to the microcontroller, bypassing the USB and battery charge controller. You can keep it on and use the device normally, but charging is limited to 500 mA instead of fast charging.

## Build and app docs

For the current setup path, start here:

- [Build Environments](../development/build-environments.md)
- [App API Reference](../reference/app-api.md)
- [System State Reference](../reference/system-state.md)

## Common issues

### My dictionary isn't working

The English dictionary is not installed out of the box and must be downloaded to the SD card. Find the dictionary files [here](https://github.com/TalismanDesign/PocketMage_PDA/tree/main/Resources/Assets/Dictionary%20(OPTED)). Connect the PocketMage to your computer with the USB app and drop all the `.txt` files into the dictionary folder.

### I can't flash the firmware

Ensure the battery is unplugged and the programming mode DIP switch is ON. See the flashing guide above.

### My SD card isn't working

First, ensure the card is 32 GB or smaller (8 GB is recommended). Next, ensure it is formatted as FAT32 with an MBR partition table. It will not work otherwise. See [Format a MicroSD Card](../tutorials/format-micro-sd.md).

### I found a software bug

Report the bug in detail on the [GitHub issues page](https://github.com/TalismanDesign/PocketMage_PDA/issues), including steps to reproduce.

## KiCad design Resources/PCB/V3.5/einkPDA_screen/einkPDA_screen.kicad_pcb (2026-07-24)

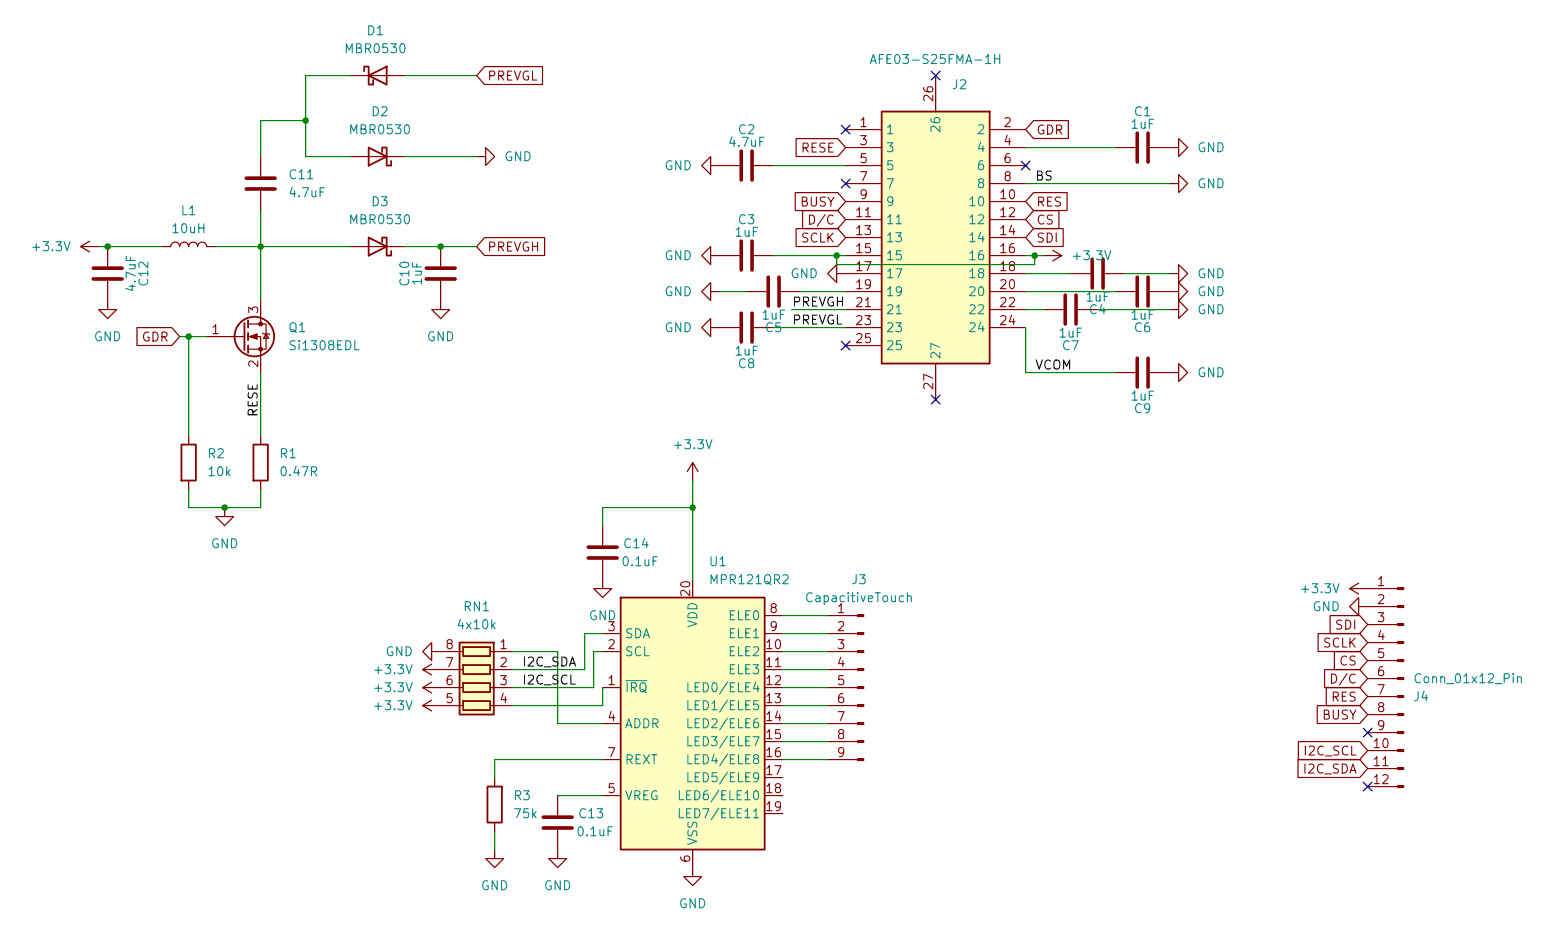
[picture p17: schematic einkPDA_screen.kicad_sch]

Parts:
C1, C3, C4, C5, C6, C7, C8, C9, C10: 1uF; C_0402_1005Metric; MPN C52923
C2, C12: 4.7uF; C_0402_1005Metric; MPN C23733
C11: 4.7uF; C_0805_2012Metric; MPN C1779
C13, C14: 0.1uF; C_0402_1005Metric; MPN C1525
D1, D2, D3: MBR0530; D_SOD-123; MPN C77336
J2: AFE03-S25FMA-1H; MPN C262544
J3: CapacitiveTouch; TouchSlider-9_50x10mm
J4: Conn_01x12_Pin; AFC01-S12FCA-00; MPN C262661
L1: 10uH; L_Cenker_CKCS5020; MPN C52281
Q1: Si1308EDL; SOT-323_SC-70; MPN C7603347
R1: 0.47R; R_0603_1608Metric; MPN C3013349
R2: 10k; R_0805_2012Metric; MPN C17414
R3: 75k; R_0603_1608Metric; MPN C23242
RN1: 4x10k; R_Array_Concave_4x0603; MPN C29718
U1: MPR121QR2; UQFN-20_3x3mm_P0.4mm; MPN C91322

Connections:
+3.3V: C3.2, C12.1, C14.1, J2.15, J2.16, J4.1, L1.1, RN1.5 (R4.2), RN1.6 (R3.2), RN1.7 (R2.2), U1.20 (VDD)
/VCOM: C9.2, J2.24
BUSY: J2.9, J4.8
CS: J2.12, J4.5
D/C: J2.11, J4.6
GDR: J2.2, Q1.1 (G), R2.1
GND: C1.2, C2.1, C3.1, C4.1, C5.2, C6.1, C7.1, C8.2, C9.1, C10.1, C12.2, C13.2, C14.2, D2.1 (K), J2.8, J2.17, J4.2, R1.2, R2.2, R3.1, RN1.8 (R1.2), U1.6 (VSS)
I2C_SCL: J4.10, RN1.3 (R3.1), U1.2 (SCL)
I2C_SDA: J4.11, RN1.2 (R2.1), U1.3 (SDA)
unnamed: C1.1, J2.4
unnamed: C2.2, J2.5
unnamed: C4.2, J2.18
unnamed: C5.1, J2.19
unnamed: C6.2, J2.20
unnamed: C7.2, J2.22
unnamed: C11.1, D1.1 (K), D2.2 (A)
unnamed: C11.2, D3.2 (A), L1.2, Q1.3 (D)
unnamed: J3.1, U1.8 (ELE0)
unnamed: J3.2, U1.9 (ELE1)
unnamed: J3.3, U1.10 (ELE2)
unnamed: J3.4, U1.11 (ELE3)
unnamed: J3.5, U1.12 (LED0/ELE4)
unnamed: J3.6, U1.13 (LED1/ELE5)
unnamed: J3.7, U1.14 (LED2/ELE6)
unnamed: J3.8, U1.15 (LED3/ELE7)
unnamed: J3.9, U1.16 (LED4/ELE8)
unnamed: RN1.1 (R1.1), U1.4 (ADDR)
unnamed: RN1.4 (R4.1), U1.1 (~IRQ)
unnamed: R3.2, U1.7 (REXT)
unnamed: C13.1, U1.5 (VREG)
PREVGH: C10.2, D3.1 (K), J2.21
PREVGL: C8.1, D1.2 (A), J2.23
RES: J2.10, J4.7
RESE: J2.3, Q1.2 (S), R1.1
SCLK: J2.13, J4.4
SDI: J2.14, J4.3

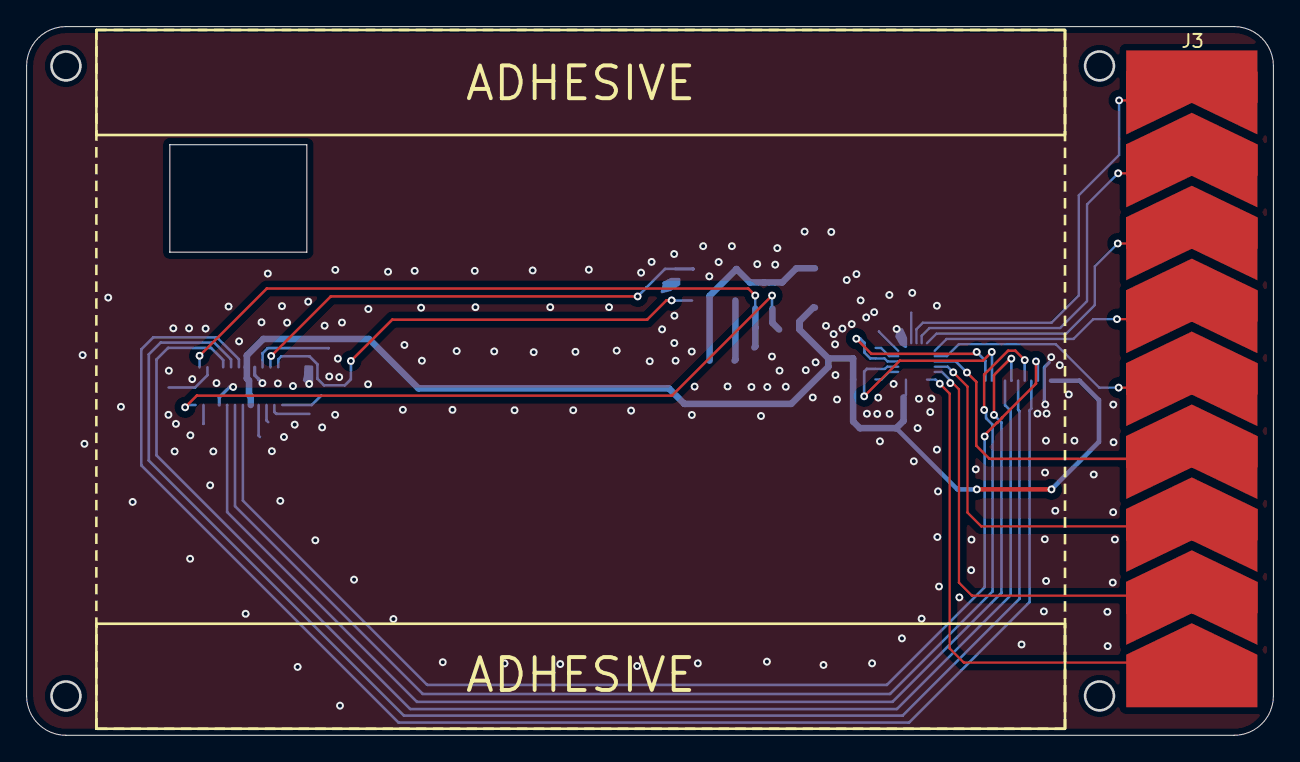
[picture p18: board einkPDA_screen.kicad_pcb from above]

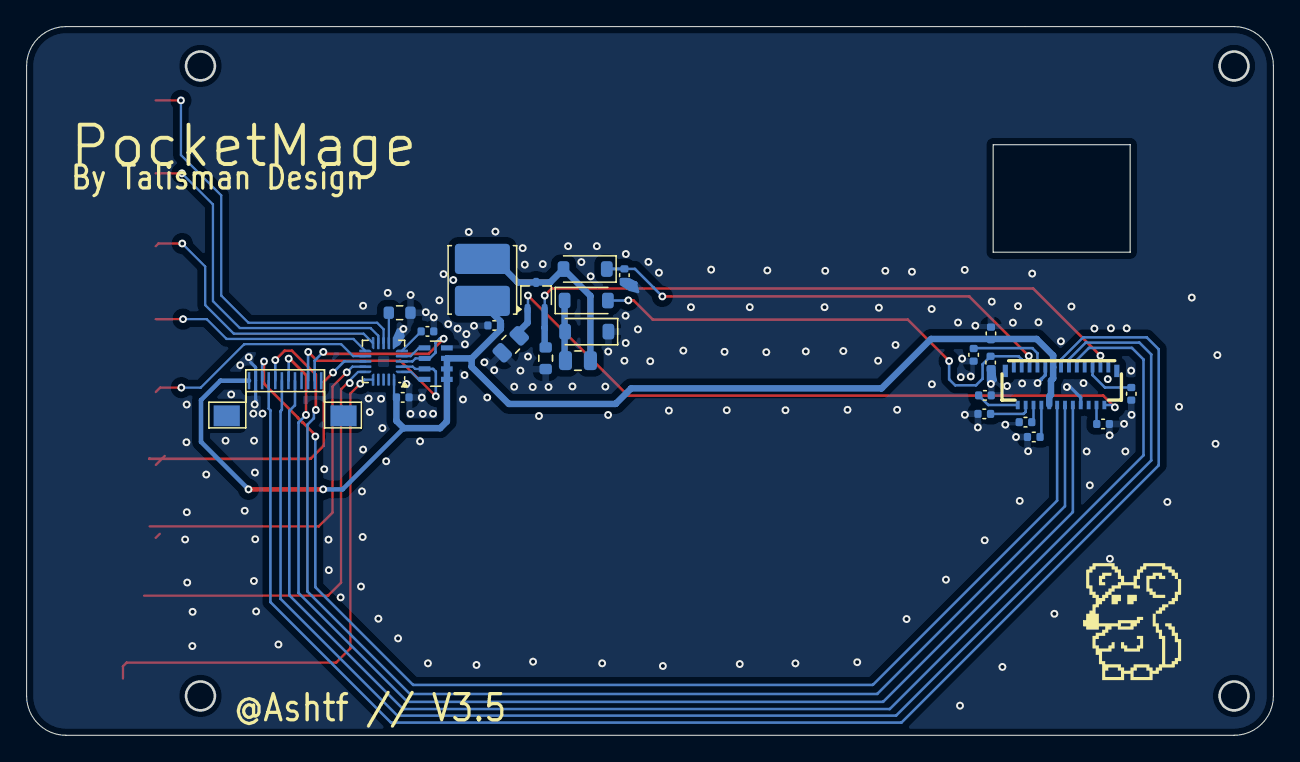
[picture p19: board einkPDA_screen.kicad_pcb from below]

Board: 2 copper layers, 95.0 x 54.0 mm, 27 parts (26 on the bottom side), 36 nets.

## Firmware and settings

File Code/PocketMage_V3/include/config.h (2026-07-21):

#ifndef CONFIG_H
#define CONFIG_H

// OTA App
// Is this an OTA APP? // OTA_APP: set -DOTA_APP_FLAG=1 in platformio.ini
#if OTA_APP_FLAG
#define OTA_APP true
#else
#define OTA_APP false
#endif

// CONFIGURATION & SETTINGS
////////////////////////////////////////////////////////////////////////////////////////////////////////////////////////////|
#define KB_COOLDOWN 3                           // Keypress cooldown
#define MAX_FILES 10                            // Number of files to store
#define FORMAT_SPIFFS_IF_FAILED true            // Format the SPIFFS filesystem if mount fails
#define SLEEPMODE "TEXT"                        // TEXT, SPLASH, CLOCK
#define TXT_APP_STYLE 1                         // 0: Old Style (NOT SUPPORTED), 1: New Style
#define SET_CLOCK_ON_UPLOAD false               // Should system clock be set automatically on code upload?
#define TOUCH_TIMEOUT_MS 1200                   // Delay after scrolling to return to typing mode (ms)
#define SYS_METADATA_FILE "/sys/SDMMC_META.txt" // File path to the file system metadata file
#define POWER_SAVE_FREQ 40                      // CPU freq for power save mode
#define IDLE_TIME 20000                         // time to wait for mage idle (ms)

// Full refresh after N partial refreshes (CHANGE WITH CAUTION)
#if POCKETMAGE_HW_VERSION == 2
  #define FULL_REFRESH_AFTER 10 // Prod uses N=10                    
#else
  #define FULL_REFRESH_AFTER 5  // Beta needs N=5
#endif
////////////////////////////////////////////////////////////////////////////////////////////////////////////////////////////|

// PIN DEFINITION
#define I2C_SCL       35
#define I2C_SDA       36
#define SWITCHED_I2C_SDA  42
#define SWITCHED_I2C_SCL  48
#define MPR121_ADDR   0x5A
#define MP2722_ADDR   0x3F
#define USB_MUX_PIN   7

#define KB_IRQ        8
#define PWR_BTN       0 
#define BAT_SENS      4
#define CHRG_SENS     39
#define RTC_INT       1 
#define LOAD_SWITCH   38

// SPI
#define SPI_MOSI      14
#define SPI_SCK       15

// OLED
#define OLED_CS       47
#define OLED_DC       46
#define OLED_RST      45

// E Ink
#define EPD_CS        2
#define EPD_DC        21
#define EPD_RST       9
#define EPD_BUSY      37

// SDMMC mode
#define SD_CLK        12
#define SD_CMD        11
#define SD_D0         13
#define SD_D1         5
#define SD_D2         6
#define SD_D3         10

// SDSPI mode
#define SD_CS         10
#define SD_MOSI       11
#define SD_SCK        12
#define SD_MISO       13

#define BZ_PIN        17

// ===================== SYSTEM SETTINGS =====================
// Persistent preferences
extern int TIMEOUT;              // Auto sleep timeout (seconds)
extern bool DEBUG_VERBOSE;       // Extra debug output
extern bool SYSTEM_CLOCK;        // Show clock on screen
extern bool SHOW_YEAR;           // Show year in clock
extern bool SAVE_POWER;          // Enable power saving mode
extern bool ALLOW_NO_MICROSD;    // Allow running without SD card
extern bool HOME_ON_BOOT;        // Start home app on boot
extern int OLED_BRIGHTNESS;      // OLED brightness (0-255)
extern int OLED_MAX_FPS;         // OLED max FPS
extern bool SD_SPI_COMPATIBILITY;

#endif

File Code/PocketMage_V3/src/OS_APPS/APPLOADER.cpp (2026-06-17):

// AUDIT 1
#include <globals.h>
#include <ESP32-targz.h>
#include <Update.h>
#include "esp_ota_ops.h"


#define APP_DIRECTORY   "/apps"
#define TEMP_DIR        "/apps/temp"
#define PREFS_NAMESPACE "AppLoader"
#if !OTA_APP // POCKETMAGE_OS
static String currentLine = "";

enum AppLoaderState {MENU, SWAP_OR_EDIT, INSTALLING, SWAP};
AppLoaderState CurrentAppLoaderState = MENU;

uint8_t selectedSlot = 0; //1:A, 2:B, etc.

// ---------- Globals ----------
volatile uint8_t g_installProgress = 0; // 0-100 (0-50: extract, 50-100: intall)
volatile bool g_installDone = false;
volatile bool g_installFailed = false;

// ---------- Utilities ----------
static bool ensureDir(fs::FS &fs, const char *path) {
    if (fs.exists(path)) return true;
    return fs.mkdir(path);
}

static bool rmRF(fs::FS &fs, const char *path) {
    File entry = fs.open(path);
    if (!entry) return true; // nothing to delete
    if (!entry.isDirectory()) {
        entry.close();
        return fs.remove(path);
    }

    File child;
    while ((child = entry.openNextFile())) {
        String childPath = String(path) + "/" + child.name();
        child.close();
        if (!rmRF(fs, childPath.c_str())) { entry.close(); return false; }
    }
    entry.close();
    return fs.rmdir(path);
}

bool copyFile(fs::FS &fs, const char *src, const char *dst) {
  File in = fs.open(src, "r");
  if (!in) return false;

  File out = fs.open(dst, "w");
  if (!out) { in.close(); return false; }

  uint8_t buf[1024];
  while (in.available()) {
    size_t r = in.read(buf, sizeof(buf));
    if (out.write(buf, r) != r) {
      in.close(); out.close();
      return false;
    }
    vTaskDelay(1); // feed watchdog
  }

  in.close();
  out.close();
  return true;
}

// ---------- Place this at the top of the .cpp file, before installTask ----------
void copyDirRecursive(File src, const String &assetsSrc, const String &assetsDst) {
    while (true) {
        File entry = src.openNextFile();
        if (!entry) break;

        String name = entry.name();
        
        // Skip macOS metadata files
        if (name.startsWith("._")) {
            entry.close();
            continue;
        }

        String relative = name.substring(assetsSrc.length());
        String dstFile = assetsDst + relative;

        if (entry.isDirectory()) {
            ensureDir(*global_fs, dstFile.c_str());
            copyDirRecursive(entry, assetsSrc, assetsDst);
        } else {
            File dst = global_fs->open(dstFile.c_str(), FILE_WRITE);
            if (dst) {
                uint8_t buf[512];
                size_t len;
                while ((len = entry.read(buf, sizeof(buf))) > 0) {
                    dst.write(buf, len);
                }
                dst.close();
                Serial.printf("Copied %s -> %s\n", name.c_str(), dstFile.c_str());
            } else {
                Serial.printf("Failed to open destination file %s\n", dstFile.c_str());
            }
        }
        entry.close();
        
        vTaskDelay(1); 
    }
}

bool copyAssetsFlat(fs::FS &fs, const char *srcDir, const char *dstDir) {
  ensureDir(fs, dstDir);

  File dir = fs.open(srcDir);
  if (!dir || !dir.isDirectory()) return false;

  File f;
  while ((f = dir.openNextFile())) {
    String name = String(f.name());
    
    // Skip macOS metadata files
    if (name.startsWith("._")) {
        f.close();
        continue;
    }

    String srcPath = String(srcDir) + "/" + name;
    String dstPath = String(dstDir) + "/" + name;

    if (f.isDirectory()) {
      ensureDir(fs, dstPath.c_str());
      copyAssetsFlat(fs, srcPath.c_str(), dstPath.c_str());
    } else {
      if (!copyFile(fs, srcPath.c_str(), dstPath.c_str())) {
        f.close();
        dir.close();
        return false;
      }
    }
    f.close();
    vTaskDelay(1);
  }
  dir.close();
  return true;
}


static String basenameNoExt(const String &path, const char *ext = ".tar") {
  int slash = path.lastIndexOf('/');
  String name = (slash >= 0) ? path.substring(slash + 1) : path;
  if (name.endsWith(ext)) return name.substring(0, name.length() - (int)strlen(ext));
  return name;
}

// Join two paths safely (ensures exactly one slash between them)
static String pathJoin(const String &a, const String &b) {
  if (a.length() == 0) return b;
  if (b.length() == 0) return a;
  if (a.endsWith("/")) {
    if (b.startsWith("/")) return a + b.substring(1); // avoid double slash
    return a + b;
  } else {
    if (b.startsWith("/")) return a + b;
    return a + "/" + b;
  }
}

// ---------- Saving/Loading appInfo ----------
#define APP_ICON_BYTES 200  // 40x40 monochrome = 200 bytes

struct AppInfo {
  char name[32];       // App name
  char tarPath[64];    // Path to .tar file
  char iconPath[64];   // Path to extracted icon.bmp (in /apps/temp or similar)
};

bool saveAppInfo(int otaIndex, const AppInfo &info) {
  String key = "OTA" + String(otaIndex);
  prefs.begin("PocketMage", false);
  bool ok = prefs.putBytes(key.c_str(), &info, sizeof(info)) == sizeof(info);
  prefs.end();
  return ok;
}

bool loadAppInfo(int otaIndex, AppInfo &info) {
  String key = "OTA" + String(otaIndex);
  prefs.begin("PocketMage", true);
  size_t n = prefs.getBytes(key.c_str(), &info, sizeof(info));
  prefs.end();
  return n == sizeof(info);
}

void loadAndDrawAppIcon(int x, int y, int otaIndex, bool showName, int maxNameChars) {
  pocketmage::setCpuSpeed(240);

  AppInfo app;
  if (!loadAppInfo(otaIndex, app)) {
    // Ensure CPU speed is reset if we abort early
    if (SAVE_POWER) pocketmage::setCpuSpeed(POWER_SAVE_FREQ);
    return;
  }

  bool iconLoaded = false;
  uint8_t buf[40 * 5]; // 40x40 1-bit = 200 bytes

  if (global_fs->exists(app.iconPath)) {
    File f = global_fs->open(app.iconPath, "r");
    if (f) {
      if (f.read(buf, sizeof(buf)) == sizeof(buf)) {
        iconLoaded = true;
      }
      f.close();
    }
  }

  display.fillRect(x, y, 40, 40, GxEPD_WHITE);

  if (iconLoaded) {
    display.drawBitmap(x, y, buf, 40, 40, GxEPD_BLACK);
  } else {
    display.drawBitmap(x, y, noIcon, 40, 40, GxEPD_BLACK);
  }

  if (showName) {
    // Make a copy and truncate
    String appNameStr = String(app.name);
    if (appNameStr.length() > maxNameChars) {
        appNameStr = appNameStr.substring(0, maxNameChars);
    }

    u8g2f.setFont(u8g2_font_ncenR10_tf);
    u8g2f.setFontMode(1);
    u8g2f.setForegroundColor(GxEPD_BLACK);

    int w = u8g2f.getUTF8Width(appNameStr.c_str());

    int tx = x + (40 - w) / 2;
    int ty = y + 40 + 13;

    u8g2f.setCursor(tx, ty);
    u8g2f.print(appNameStr);
  }

  if (SAVE_POWER) pocketmage::setCpuSpeed(POWER_SAVE_FREQ);
}
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

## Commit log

2026-03-29 Add detailed fail messages for USB
    [USB.cpp]
2026-04-02 PCB updates
2026-04-03 PCB V3.3
    [bom.csv, designators.csv, einkPDA_keyboard.kicad_sch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]
2026-04-09 Update PCBs
2026-04-13 Fix critical battery charge current bug
2026-05-02 Update wiring for load switch
    [einkPDA_keyboard.kicad_sch]
2026-05-03 Rename Folder
    [YTS-C017-2B.step, bom.csv, designators.csv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]
2026-05-03 Fix startup issue for production boards
2026-07-05 Add FDM-Friendly Case Files
    [batteryDoorFDM.step, bottomFrameFDM.step, frameLidFDM.step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]
2026-07-10 docs: add CONTRIBUTING.md
    Covers build setup (PlatformIO envs), the current lack of an automated
    test suite, coding conventions (centralised pin config, app-dispatch
    switch pattern, shared-state caveat), the PR process, third-party
    Bazaar app development, and AI-assisted contributions.
2026-07-24 Keyboard PCB power system update
    [einkPDA_keyboard.kicad_sch]
2026-07-24 Update versioning
    [YTS-C017-2B.step, bom.csv, designators.csv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]
